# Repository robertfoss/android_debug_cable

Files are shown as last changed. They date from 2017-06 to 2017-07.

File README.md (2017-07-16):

# Android Debug Cable

v0.5 front

## Connector

    ####|###|==|==>
    3.3V GND RX  TX

## Changelog

v0.7:
 - Fix VBUS being unconnected
 - Shrink connector holes

v0.6:
- Fix C1 to be actually decoupling

v0.5:
- Switch to throughole 3.5mm connector

v0.4:
- Cost reductions:
  * Switch to male 3.5mm connector
  * Switch from CP2103 to CP2102N
  * Switch to cheaper 1.8v reg
  * Switch to only one cap value
  * Smaller PCB

v0.3:

- Changed 3.5mm connector mechanical hole to have no copper

v0.2:

- Moved logo position
- Moved a via to make space for a more centered logo
- Moved RX/TX/GND/V3.3 text
- Updated verion text
- Increased outline corner radius
- Increased board width with 0.02mm to 12.2mm
- Switched RX/TX pins on 3.5mm connector

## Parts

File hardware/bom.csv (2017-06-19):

Qty | MPN | Purchase URL | Designator
1 | CP2102N-A01-GQFN24 | https://octopart.com/cp2102n-a01-gqfn24-silicon+labs-74636023 | U2
1 | 50-00397 | https://octopart.com/50-00397-tensility-46948686 | P2
4 | CC0402KRX5R5BB105 | https://octopart.com/cc0402krx5r5bb105-yageo-42244618 | C1,C2,C3,C4
1 | RC0402FR-0710KL | https://octopart.com/rc0402fr-0710kl-yageo-55458461 | R1
1 | 105017-0001 | https://octopart.com/105017-0001-molex-18688631 | P1
1 | TCR2EF18,LM(CT | https://octopart.com/tcr2ef18%2Clm%28ct-toshiba-51163354 | U1

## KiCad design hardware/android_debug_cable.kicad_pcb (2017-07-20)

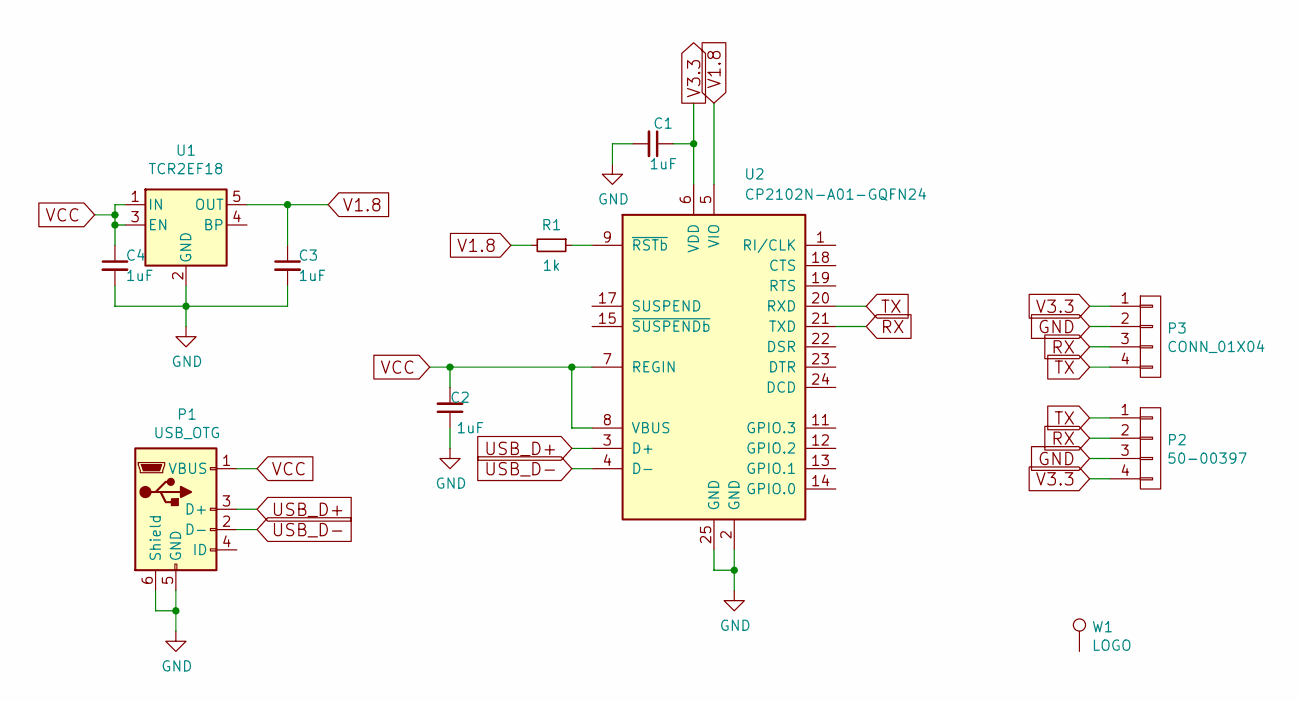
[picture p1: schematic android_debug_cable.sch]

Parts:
C1: 1uF
C2, C3, C4: 1uF; C_0402
P1: USB_OTG; USB_Micro-B
P2: 50-00397
P3: CONN_01X04; CONN_2.54mm_1x4_no-outline
R1: 1k; R_0402
U1: TCR2EF18; SOT-23-5
U2: CP2102N-A01-GQFN24; QFN-24-1EP_4x4mm_Pitch0.5mm
W1: LOGO; copperhead_logo

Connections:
GND: C1.2, C2.1, C3.2, C4.2, P1.5 (GND), P1.6 (Shield), P2.3, P3.2, U1.2 (GND), U2.2 (GND), U2.25 (GND)
unnamed: R1.1, U2.9 (~RSTb)
RX: P2.2, P3.3, U2.21 (TXD)
TX: P2.1, P3.4, U2.20 (RXD)
USB_D+: P1.3 (D+), U2.3 (D+)
USB_D-: P1.2 (D-), U2.4 (D-)
V1.8: C3.1, R1.2, U1.5 (OUT), U2.5 (VIO)
V3.3: C1.1, P2.4, P3.1, U2.6 (VDD)
VCC: C2.2, C4.1, P1.1 (VBUS), U1.1 (IN), U1.3 (EN), U2.7 (REGIN), U2.8 (VBUS)

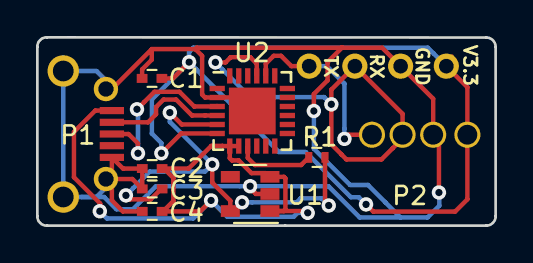
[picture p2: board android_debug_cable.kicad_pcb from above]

Board: 2 copper layers, 25.5 x 10.5 mm, 11 parts (1 on the bottom side), 9 nets.

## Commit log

2016-08-14 v0.1 with copperhead branding
    [android_debug_cable.kicad_pcb, android_debug_cable.sch]
2016-08-14 Added gerbers for v0.1_copperhead
    [android_debug_cable-B.Cu.gbl, android_debug_cable-B.Mask.gbs, android_debug_cable-B.SilkS.gbo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]
2016-08-31 Add v0.2
    [android_debug_cable.kicad_pcb, android_debug_cable.sch]
2016-08-31 Add v0.2_copperhead
    [android_debug_cable.kicad_pcb, android_debug_cable.sch]
2016-10-03 Updated 3.5mm connector footprint
    [android_debug_cable.kicad_pcb]
2016-10-03 Switch images
2017-01-12 Remove Copperhead branding, bump to v0.3
    [android_debug_cable-B.Cu.gbl, android_debug_cable-B.Fab.gbr, android_debug_cable-B.SilkS.gbo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]
2017-06-19 Add Seeed compatible bom
    [bom.csv]
2017-06-20 Add first version of v0.4
    [android_debug_cable.kicad_pcb, android_debug_cable.sch]
2017-06-20 Add connector info
2017-06-20 Switch to v0.4 render
2017-06-20 Change direction of connector info
2017-06-20 Changed 3.5mm connector pinout
    [android_debug_cable-B.Cu.gbl, android_debug_cable-B.Fab.gbr, android_debug_cable-B.Mask.gbs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]
2017-06-20 Fixed CP2102N power sourcing
    [android_debug_cable.kicad_pcb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]
2017-06-21 Edit MicoUSB footprint
    [android_debug_cable.kicad_pcb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]
2017-06-21 Move vias away from logo
    [android_debug_cable.kicad_pcb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]
2017-06-27 Add 54-00035 connector files
2017-06-27 Add v0.5 using throughole 3.5mm connector
    [android_debug_cable.kicad_pcb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]
2017-07-01 Move logo/version number around
    [android_debug_cable.kicad_pcb]
2017-07-19 54-00035: shrunk holes
2017-07-19 Fixed VBUS not being connected, shrunk connector through holes
    [android_debug_cable.kicad_pcb, android_debug_cable.sch]
